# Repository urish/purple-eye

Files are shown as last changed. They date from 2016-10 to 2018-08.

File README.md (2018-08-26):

purple-eye
==========

> A web-bluetooth controlled 3d-printed dancing robot

Purple Eye

## Prerequisites

The Web Interface uses [Web Bluetooth](https://medium.com/@urish/start-building-with-web-bluetooth-and-progressive-web-apps-6534835959a6) and is available on Chrome on the following platforms:

* Android 6.0 or newer
* Mac OS X 10.10 or newer
* Recent Linux ([see here for details](https://acassis.wordpress.com/2016/06/28/how-to-get-chrome-web-bluetooth-working-on-linux/))
* Windows 10 (Chrome Canary only)
* Chrome OS

[Online Web Interface](https://urish.github.io/purple-eye/)

## Hardware

➡ [Read how to make your own "Purple Eye" robot](https://medium.com/@urish/making-purple-eye-diy-dancing-robot-fa03d0f658e2#.q7gzas4cq)

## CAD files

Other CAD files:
model/purple-eye.blend

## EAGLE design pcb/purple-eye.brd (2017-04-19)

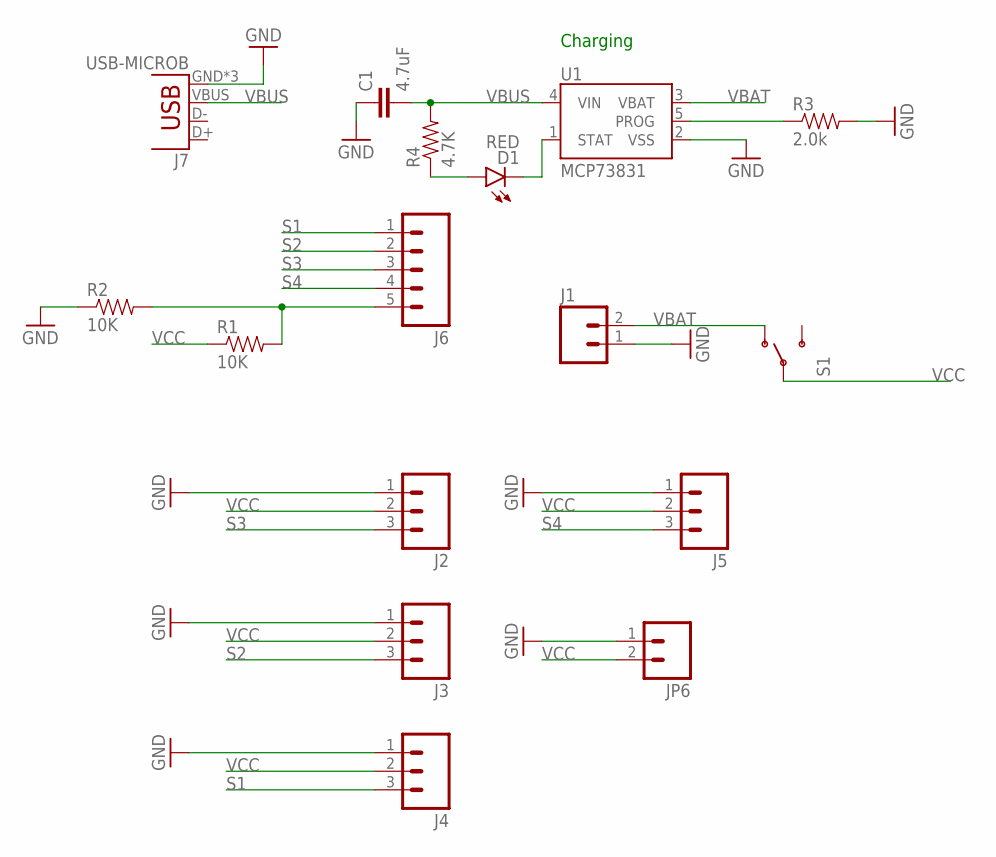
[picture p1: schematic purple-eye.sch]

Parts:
C1: 4.7uF; 0603-CAP
D1: RED; LED-0603
J1: M02JST-PTH-2; JST-2-PTH
J2, J3, J4, J5: M03LOCK; 1X03_LOCK
J6: M05LOCK; 1X05_LOCK
J7: USB-MICROB
JP6: M02LOCK; 1X02_LOCK
R1, R2: 10K; 0603-RES
R3: 2.0k; 0603-RES
R4: 4.7K; 0603-RES
S1: SWITCH-SPDTPTH_LOCK; SWITCH-SPDT_LOCK.007S
U1: MCP73831; SOT23-5

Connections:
GND: C1.1, J1.1, J2.1, J3.1, J4.1, J5.1, J7.GND, J7.MT1 (GND), J7.MT2 (GND), JP6.1, R2.1, R3.2, U1.2 (VSS)
unnamed: J6.5, R1.2, R2.2
unnamed: R3.1, U1.5 (PROG)
unnamed: D1.A, R4.1
unnamed: D1.C, U1.1 (STAT)
S1: J4.3, J6.1
S2: J3.3, J6.2
S3: J2.3, J6.3
S4: J5.3, J6.4
VBAT: J1.2, S1.1 (O), U1.3 (VBAT)
VBUS: C1.2, J7.VBUS, R4.2, U1.4 (VIN)
VCC: J2.2, J3.2, J4.2, J5.2, JP6.2, R1.1, S1.2

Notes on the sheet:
Charging

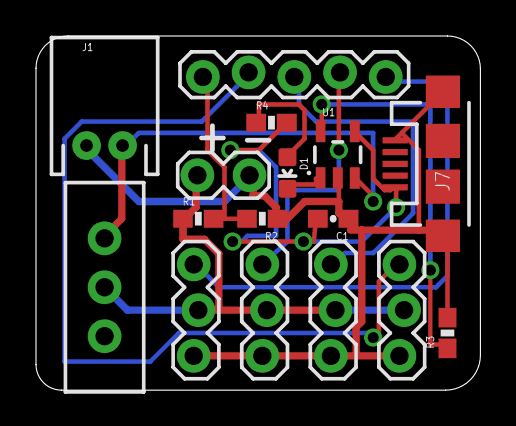
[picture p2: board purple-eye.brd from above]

Board: 2 copper layers, 24.7 x 19.7 mm, 16 parts (0 on the bottom side), 12 nets.

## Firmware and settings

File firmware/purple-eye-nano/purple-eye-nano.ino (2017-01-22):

/**
   Purple Eye Firmware ported to [BLE Nano](http://redbearlab.com/blenano/)
   Copyright (C) 2016, Uri Shaked
   License: MIT.
*/

extern "C" {
#include "pstorage.h"
#include "fstorage.h"
#include "softdevice_handler.h"
}

#include <BLE_API.h>
#include <Wire.h>
#include <LSM303.h>
#include <L3G.h>
#include "nrf51servo.h"

#define DEVICE_NAME       "PurpleEye"
#define RIGHT_LEG_PIN     D4
#define RIGHT_FOOT_PIN    D5
#define LEFT_FOOT_PIN     D6
#define LEFT_LEG_PIN      D7
#define BATTERY_LEVEL_PIN A5

// Physical Web
#define EDDYSTONE_SERVICE_UUID 0xFEAA
uint8_t eddystoneData[]  = {
  0xAA, 0xFE,  // Eddystone Service Id
  0x10,        // Frame type: URL
  0xF8,        // Power
  0x03,        // https://
  'b', 'i', 't', '.', 'd', 'o', '/', 'p', 'r', 'p', 'l',
};

// ng-beacon scanning parameters
#define RSSI_THRESHOLD -50
#define TARGET_DEVICE_NAME "ng-beacon"

BLE    ble;
static const uint16_t advertisedServices[] = { GattService::UUID_BATTERY_SERVICE, 0x5100, EDDYSTONE_SERVICE_UUID };

// Servos
Servo              leftFoot, rightFoot, leftLeg, rightLeg;
static uint8_t     servoValues[4]         = {0, 0, 0, 0};
GattCharacteristic servosChar(0x5200, servoValues, sizeof(servoValues), sizeof(servoValues), GattCharacteristic::BLE_GATT_CHAR_PROPERTIES_WRITE | GattCharacteristic::BLE_GATT_CHAR_PROPERTIES_WRITE_WITHOUT_RESPONSE);
static int8_t      servoOffsets[4]        = {0, 0, 0, 0};
GattCharacteristic servoOffsetsChar(0x5201, (uint8_t*)servoOffsets, sizeof(servoOffsets), sizeof(servoOffsets), GattCharacteristic::BLE_GATT_CHAR_PROPERTIES_READ | GattCharacteristic::BLE_GATT_CHAR_PROPERTIES_WRITE | GattCharacteristic::BLE_GATT_CHAR_PROPERTIES_WRITE_WITHOUT_RESPONSE);
GattCharacteristic *servosChars[] = {&servosChar, &servoOffsetsChar, };
GattService        servosService(0x5100, servosChars, sizeof(servosChars) / sizeof(GattCharacteristic *));

// Battery
Ticker             batteryTask;
static uint8_t     batteryLevel[1];
GattCharacteristic batteryLevelChar(GattCharacteristic::UUID_BATTERY_LEVEL_CHAR, batteryLevel, sizeof(batteryLevel), sizeof(batteryLevel), GattCharacteristic::BLE_GATT_CHAR_PROPERTIES_READ | GattCharacteristic::BLE_GATT_CHAR_PROPERTIES_NOTIFY);
GattCharacteristic *batteryServiceChars[] = {&batteryLevelChar };
GattService        batteryService(GattService::UUID_BATTERY_SERVICE, batteryServiceChars, sizeof(batteryServiceChars) / sizeof(GattCharacteristic *));

// Accelerometer + Magnetometer + Gyro (IMU)
LSM303             imuDevice;
bool               imuAvailable;
L3G                gyro;
bool               gyroAvailable;
static uint16_t    imuData[9] = {0, 0, 0, 0, 0, 0, 0, 0, 0};
GattCharacteristic imuChar(0xff09, (uint8_t*)imuData, sizeof(imuData), sizeof(imuData), GattCharacteristic::BLE_GATT_CHAR_PROPERTIES_READ | GattCharacteristic::BLE_GATT_CHAR_PROPERTIES_NOTIFY);
GattCharacteristic *imuChars[] = {&imuChar };
GattService        imuService(0xff08, imuChars, sizeof(imuChars) / sizeof(GattCharacteristic *));

// Sound
byte               playerData[] = {0, 0, 0};
GattCharacteristic playerChar(0xff1a, (uint8_t*)playerData, sizeof(playerData), sizeof(playerData), GattCharacteristic::BLE_GATT_CHAR_PROPERTIES_WRITE | GattCharacteristic::BLE_GATT_CHAR_PROPERTIES_WRITE_WITHOUT_RESPONSE);
GattCharacteristic *playerChars[] = {&playerChar };
GattService        playerService(0xff10, playerChars, sizeof(playerChars) / sizeof(GattCharacteristic *));

// Storage
bool               storageAvailable = false;
FS_SECTION_VARS_ADD(fs_config_t storageConfig) = { .cb = &storageCallback, .num_pages = 1, .page_order = 1 };

// Dancer
Ticker             danceTask;
int8_t             dancePosition = 0;
int8_t             danceDirection = 1;

void updateServos() {
  if (servoValues[0] == 0 && servoValues[1] == 0 && servoValues[2] == 0 && servoValues[3] == 0) {
    rightLeg.detach();
    rightFoot.detach();
    leftFoot.detach();
    leftLeg.detach();
  } else {
    if (!leftFoot.attached()) {
      rightLeg.attach(RIGHT_LEG_PIN);
      rightFoot.attach(RIGHT_FOOT_PIN);
      leftFoot.attach(LEFT_FOOT_PIN);
      leftLeg.attach(LEFT_LEG_PIN);
    }
    rightLeg.write(servoValues[0] + servoOffsets[0]);
    rightFoot.write(servoValues[1] + servoOffsets[1]);
    leftFoot.write(servoValues[2] + servoOffsets[2]);
    leftLeg.write(servoValues[3] + servoOffsets[3]);
  }
}

static void sysEventHandler(uint32_t sys_evt) {
  // Delegate events to the fstorage module, as well as pstorage (used by the RBL stack)
  fs_sys_event_handler(sys_evt);
  pstorage_sys_event_handler(sys_evt);
}

static void storageCallback(uint8_t op_code, uint32_t result, uint32_t  const * p_data, fs_length_t length) {
  if (op_code == FS_OP_ERASE && result == NRF_SUCCESS) {
    fs_store(&storageConfig, storageConfig.p_start_addr, (uint32_t*)servoOffsets, 1); // 1 words = 4 bytes
  }
}

void loadServoOffsets() {
  memcpy(servoOffsets, storageConfig.p_start_addr, sizeof(servoOffsets));
}

void saveServoOffsets() {
  fs_erase(&storageConfig, storageConfig.p_start_addr, FS_PAGE_SIZE_WORDS);
}

void playerCommand(byte cmd, byte arg1, byte arg2) {
  byte data[10] = {0x7e, 0xff, 0x6, cmd, 0, arg1, arg2, 0, 0, 0xef};
  int16_t checksum = 0 - data[1] - data[2] - data[3] - data[4] - data[5] - data[6];
  data[7] = (checksum >> 8) & 0xff;
  data[8] = checksum & 0xff;
  Serial.write(data, sizeof(data));
}

void playerCommand(byte cmd, uint16_t arg) {
  playerCommand(cmd, arg >> 8, arg & 0xff);
}

void playSound(uint16_t fileNum, byte volume) {
  if (volume > 0) {
    playerCommand(0x6, 0, volume);
    delay(10);
  }
  playerCommand(0x3, fileNum);
}

void disconnectionCallBack(const Gap::DisconnectionCallbackParams_t *params) {
  ble.startAdvertising();
  Serial.println("Disconnected :-(");
}

void gattServerWriteCallBack(const GattWriteCallbackParams *params) {
  if (params->handle == servosChar.getValueAttribute().getHandle()) {
    memcpy(servoValues, params->data, params->len);
    updateServos();
  }
  if (params->handle == servoOffsetsChar.getValueAttribute().getHandle()) {
    memcpy(servoOffsets, params->data, params->len);
    saveServoOffsets();
  }
  if ((params->handle == playerChar.getValueAttribute().getHandle()) && (params->len >= 2)) {
    uint16_t fileId = *(uint16_t*)params->data;
    uint8_t volume = params->len == 3 ? params->data[2] : 0;
    playSound(fileId, volume);
  }
}

void sensorsCallback() {
  if (ble.getGapState().connected) {
    // Battery Level
    float voltage = analogRead(BATTERY_LEVEL_PIN) * 3.3 / 512;
    batteryLevel[0] = max(0, min(100, (int)((voltage - 3.6) / 0.6 * 100)));
    ble.updateCharacteristicValue(batteryLevelChar.getValueAttribute().getHandle(), batteryLevel, sizeof(batteryLevel));

    // IMU
    if (imuAvailable) {
      imuDevice.read();
      memset(imuData, 0, sizeof(imuData));
      if (!imuDevice.timeoutOccurred()) {
        imuData[0] = imuDevice.a.x;
        imuData[1] = imuDevice.a.y;
        imuData[2] = imuDevice.a.z;
        imuData[3] = imuDevice.m.x;
        imuData[4] = imuDevice.m.y;
        imuData[5] = imuDevice.m.z;
      }
      if (gyroAvailable) {
        gyro.read();
        if (!gyro.timeoutOccurred()) {
          imuData[6] = gyro.g.x;
          imuData[7] = gyro.g.y;
          imuData[8] = gyro.g.z;
        }
      }
      ble.updateCharacteristicValue(imuChar.getValueAttribute().getHandle(), (uint8_t*)imuData, sizeof(imuData));
    }
  }
}

char *getDeviceName(const uint8_t *data, byte dlen) {
  static char result[16];
  byte index = 0;

  while (index + 1 < dlen) {
    byte field_len = data[index];
    byte field_type = data[index + 1];
    const void *field_data = &data[index + 2];
    index += field_len + 1;

    if (field_type == BLE_GAP_AD_TYPE_COMPLETE_LOCAL_NAME) {
      field_len--;
      if (field_len > 15) {
        field_len = 15;
      }
      memcpy(result, field_data, field_len);
      result[field_len] = 0;
      return result;
    }
  }

  return NULL;
}

unsigned long beaconLastSeen = millis();
void danceCallback() {
  if (millis() - 2000 > beaconLastSeen) {
    beaconLastSeen = 0;
    dancePosition = 0;
    danceTask.detach();
  }

  servoValues[0] = 90 + dancePosition;
  servoValues[1] = 90 + dancePosition;
  servoValues[2] = 90 + dancePosition;
  servoValues[3] = 90 + dancePosition;
  updateServos();

  dancePosition += danceDirection * 2;
  if (dancePosition > 20 || dancePosition < -20) {
    danceDirection = -danceDirection;
  }
}

void scanningCallback(const Gap::AdvertisementCallbackParams_t* params) {
  char *deviceName = getDeviceName((const uint8_t *)params->advertisingData, params->advertisingDataLen);
  if ((params->rssi > RSSI_THRESHOLD) && !strcmp(deviceName, TARGET_DEVICE_NAME)) {
    Serial.print("Found beacon, RSSI=");
    Serial.println(params->rssi, DEC);

    if (!beaconLastSeen) {
      danceTask.attach(danceCallback, 0.02);
    }
    beaconLastSeen = millis();
  }
}

void setup() {
  Serial.begin(9600);
  Serial.println("Purple Eye Nano!");

  // Set up storage - to store servo offsets
  // Following two lines are a workaround for a bug - storageConfig is not initialized correctly for some reason.
  // So we set up the configuration here, and override the original one.
  fs_config_t storageConfig2 = { .cb = storageCallback, .num_pages = 1, .page_order = 0 };
  memcpy(&storageConfig, &storageConfig2, sizeof(storageConfig));
  if (fs_init() == NRF_SUCCESS) {
    storageAvailable = true;
    loadServoOffsets();
  }

  Wire.begin();
  imuAvailable = imuDevice.init();
  imuDevice.setTimeout(1);
  imuDevice.enableDefault();
  gyroAvailable = gyro.init();
  gyro.setTimeout(1);
  gyro.enableDefault();

  // LED consumes about 0.3ma, so we turn it off.
  pinMode(LED, OUTPUT);
  digitalWrite(LED, 1);

  pinMode(BATTERY_LEVEL_PIN, INPUT);
  pinMode(RIGHT_LEG_PIN, OUTPUT);
  pinMode(RIGHT_FOOT_PIN, OUTPUT);
  pinMode(LEFT_FOOT_PIN, OUTPUT);
  pinMode(LEFT_LEG_PIN, OUTPUT);
  updateServos();

  ble.init();
  ble.onDisconnection(disconnectionCallBack);
  ble.onDataWritten(gattServerWriteCallBack);

  // Setup advertising payload, including Eddystone data
  ble.accumulateAdvertisingPayload(GapAdvertisingData::BREDR_NOT_SUPPORTED | GapAdvertisingData::LE_GENERAL_DISCOVERABLE);
  ble.accumulateAdvertisingPayload(GapAdvertisingData::COMPLETE_LIST_16BIT_SERVICE_IDS, (uint8_t*)advertisedServices, sizeof(advertisedServices));
  ble.accumulateAdvertisingPayload(GapAdvertisingData::SERVICE_DATA, (uint8_t*)eddystoneData, sizeof(eddystoneData));
  ble.accumulateScanResponse(GapAdvertisingData::COMPLETE_LOCAL_NAME, (uint8_t *)DEVICE_NAME, sizeof(DEVICE_NAME) - 1);
  ble.setAdvertisingType(GapAdvertisingParams::ADV_CONNECTABLE_UNDIRECTED);

  ble.addService(servosService);
  ble.addService(batteryService);
  ble.addService(imuService);
  ble.addService(playerService);
  ble.setDeviceName((const uint8_t *)DEVICE_NAME);
  ble.setTxPower(4);
  ble.setAdvertisingInterval(160); // (100 ms = 160 * 0.625ms.)
  ble.setAdvertisingTimeout(0);
  ble.startAdvertising();

  // scanning for ng-beacons
  ble.setScanParams(200, 100, 0, true);
  ble.startScan(scanningCallback);

  // Battery level task
  batteryTask.attach(sensorsCallback, 0.1);

  // Override the system event handler - this is required for fstorage
  softdevice_sys_evt_handler_set(sysEventHandler);
}

void loop() {
  ble.waitForEvent();
}

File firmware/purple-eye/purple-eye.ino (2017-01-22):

/*********************************************************************
  This is an example for our nRF51822 based Bluefruit LE modules

  Pick one up today in the adafruit shop!

  Adafruit invests time and resources providing this open source code,
  please support Adafruit and open-source hardware by purchasing
  products from Adafruit!

  MIT license, check LICENSE for more information
  All text above, and the splash screen below must be included in
  any redistribution
*********************************************************************/

#include <Arduino.h>

#include "Adafruit_BLE.h"
#include "Adafruit_BluefruitLE_SPI.h"
#include "Servo.h"

#define BLUEFRUIT_SPI_CS               8
#define BLUEFRUIT_SPI_IRQ              7
#define BLUEFRUIT_SPI_RST              4

#define RIGHT_LEG_PIN 5
#define RIGHT_FOOT_PIN 11
#define LEFT_FOOT_PIN 9
#define LEFT_LEG_PIN 10

const uint8_t BLE_ADVERTISE_PACKET[] = {
  // Eddystone URL Beacon. See https://www.mkompf.com/tech/eddystoneurl.html
  0x07,  // Length of Service List
  0x03,  // Param: Service List
  0x00, 0x51, // Purple Eye Service ID
  0x0a, 0x18, // Battery Level Service
  0xAA, 0xFE,  // Eddystone ID
  
  0x11,  // Length of Service Data
  0x16,  // Service Data
  0xAA, 0xFE, // Eddystone ID
  
  0x10,  // Frame type: URL
  0xF8, // Power
  0x02, // http://
  'b',
  'i',
  't',
  '.',
  'd',
  'o',
  '/',
  'p',
  'r',
  'p',
  'l',
};

Adafruit_BluefruitLE_SPI ble(BLUEFRUIT_SPI_CS, BLUEFRUIT_SPI_IRQ, BLUEFRUIT_SPI_RST);

Servo rightFoot, rightLeg, leftFoot, leftLeg;
int rightFootValue = 0, rightLegValue = 0, leftFootValue = 0, leftLegValue = 0;

void error(const __FlashStringHelper*err) {
  Serial.println(err);
  while (1);
}

void updateServos() {
  if (leftFootValue == 0 && leftLegValue == 0 && rightFootValue == 0 && rightFootValue == 0) {
    rightLeg.detach();
    rightFoot.detach();
    leftFoot.detach();
    leftLeg.detach();
  } else {
    if (!leftFoot.attached()) {
      rightLeg.attach(RIGHT_LEG_PIN);
      rightFoot.attach(RIGHT_FOOT_PIN);
      leftFoot.attach(LEFT_FOOT_PIN);
      leftLeg.attach(LEFT_LEG_PIN);
    }
    rightFoot.write(rightFootValue + 8);
    rightLeg.write(rightLegValue);
    leftFoot.write(leftFootValue - 10);
    leftLeg.write(leftLegValue);
  }
}

int32_t eyebotServiceId;
int32_t eyebotServosCharId;
int32_t batteryServiceId;
int32_t batteryLevelCharId;

void setup(void)
{
  boolean success;

  updateServos();

  Serial.begin(115200);
  Serial.println("Start!");

  randomSeed(micros());

  /* Initialise the module */
  Serial.print(F("Initialising the Bluefruit LE module: "));

  if ( !ble.begin(true) )
  {
    error(F("Couldn't find Bluefruit, make sure it's in CoMmanD mode & check wiring?"));
  }
  Serial.println( F("OK!") );

  /* Perform a factory reset to make sure everything is in a known state */
  Serial.println(F("Performing a factory reset: "));
  if (! ble.factoryReset() ) {
    error(F("Couldn't factory reset"));
  }

  /* Disable command echo from Bluefruit */
  ble.echo(false);

  Serial.println("Requesting Bluefruit info:");
  /* Print Bluefruit information */
  ble.info();

  /* Change the device name to make it easier to find */
  Serial.println("Setting device name");

  if (! ble.sendCommandCheckOK(F("AT+GAPDEVNAME=PurpleEye")) ) {
    error(F("Could not set device name?"));
  }

  /* Add the Servo Service definition */
  /* Service ID should be 1 */
  Serial.println(F("Adding the Servo service definition (UUID = 0x5100): "));
  success = ble.sendCommandWithIntReply( F("AT+GATTADDSERVICE=UUID=0x5100"), &eyebotServiceId);
  if (! success) {
    error(F("Could not add Servo service"));
  }

  /* Chars ID for Servo position should be 1 */
  Serial.println(F("Adding the Servo Position characteristic (UUID = 0x5200): "));
  success = ble.sendCommandWithIntReply( F("AT+GATTADDCHAR=UUID=0x5200, PROPERTIES=0x0A, MIN_LEN=4, MAX_LEN=4, VALUE=00-00-00-00"), &eyebotServosCharId);
  if (! success) {
    error(F("Could not add Servo characteristic"));
  }

  /* Add the Battery Service definition */
  /* Service ID should be 1 */
  Serial.println(F("Adding the service definition (UUID = 0x180F): "));
  success = ble.sendCommandWithIntReply( F("AT+GATTADDSERVICE=UUID=0x180F"), &batteryServiceId);
  if (! success) {
    error(F("Could not add Battery service"));
  }

  /* Chars ID for Battery Level should be 1 */
  Serial.println(F("Adding the characteristic (UUID = 0x2A19): "));
  success = ble.sendCommandWithIntReply( F("AT+GATTADDCHAR=UUID=0x2A19, PROPERTIES=0x12, MIN_LEN=1, MAX_LEN=1, VALUE=00"), &batteryLevelCharId);
  if (! success) {
    error(F("Could not add Battery Level characteristic"));
  }

  /* Add the Servo Service and Eddystone Beacon to the advertising data */
  Serial.println(F("Adding Servo Service UUID to the advertising payload: "));

  // Encode advertise packet as hex string
  char bleAdvStr[sizeof(BLE_ADVERTISE_PACKET) * 3];
  for (int i = 0; i < sizeof(BLE_ADVERTISE_PACKET); i++) {
    sprintf(&bleAdvStr[i * 3], "%02x-", BLE_ADVERTISE_PACKET[i]);
  };
  bleAdvStr[sizeof(bleAdvStr) - 1] = 0;
  char cmdBuf[256];
  snprintf(cmdBuf, sizeof(cmdBuf), "AT+GAPSETADVDATA=%s", bleAdvStr);
  ble.sendCommandCheckOK( cmdBuf );

  /* Reset the device for the new service setting changes to take effect */
  Serial.print(F("Performing a SW reset (service changes require a reset): "));
  ble.reset();

  Serial.println();
}

uint8_t lastBatteryLevel = 0;
void loop(void)
{
  float voltage = analogRead(A0) * 3.3 / 512;
  uint8_t batteryLevel = max(0, min(100, (voltage - 3.6) / 0.6 * 100));

  // Update Battery Level Charasteristic if necessary
  if (lastBatteryLevel != batteryLevel) {
    ble.print("AT+GATTCHAR=");
    ble.print(batteryLevelCharId);
    ble.print(",");
    ble.println(batteryLevel);
    ble.waitForOK();
    lastBatteryLevel = batteryLevel;
  };

  // Read servo values
  ble.print("AT+GATTCHAR=");
  ble.println(eyebotServosCharId);

  Serial.println(batteryLevel);

  char buf[100] = {0};
  ble.readline(buf, sizeof(buf));
  sscanf(buf, "%02x-%02x-%02x-%02x", &rightLegValue, &rightFootValue, &leftFootValue, &leftLegValue);
  updateServos();
}

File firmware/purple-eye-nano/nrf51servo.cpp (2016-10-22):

/** 
 *  nRF51 Servo Controller
 * 
 * Copyright (C) 2016, Uri Shaked.
 * 
 * License: MIT
 */

#include "softdevice_handler.h"
#include <Ticker.h>
#include <Arduino.h>

#include "nrf51servo.h"

#define SERVO_TIMESLOT_LENGTH  2500 // ms

static mbed::Ticker servo_task;
static uint8_t   servo_count = 0;
static uint8_t   servo_index = 0;
static Servo *servos[MAX_SERVOS] = {0};

static nrf_radio_signal_callback_return_param_t signal_callback_return_param = {0};

static nrf_radio_signal_callback_return_param_t * radio_callback(uint8_t signal_type)
{
  uint16_t next_tick = 0;
  uint16_t servo_tick_counter = 0;

  switch (signal_type)
  {
    case NRF_RADIO_CALLBACK_SIGNAL_TYPE_START:
      signal_callback_return_param.params.request.p_next = NULL;
      signal_callback_return_param.callback_action = NRF_RADIO_SIGNAL_CALLBACK_ACTION_END;

      servo_index++;
      if (servo_index >= servo_count) {
        servo_index = 0;
      }

      digitalWrite(servos[servo_index]->getPin(), HIGH);
      delayMicroseconds(servos[servo_index]->readMicroseconds());
      digitalWrite(servos[servo_index]->getPin(), LOW);
      break;

    case NRF_RADIO_CALLBACK_SIGNAL_TYPE_RADIO:
      signal_callback_return_param.params.request.p_next = NULL;
      signal_callback_return_param.callback_action = NRF_RADIO_SIGNAL_CALLBACK_ACTION_NONE;
      break;

    case NRF_RADIO_CALLBACK_SIGNAL_TYPE_TIMER0:
      signal_callback_return_param.callback_action = NRF_RADIO_SIGNAL_CALLBACK_ACTION_END;
      signal_callback_return_param.params.request.p_next = NULL;
      break;

    default:
      signal_callback_return_param.callback_action = NRF_RADIO_SIGNAL_CALLBACK_ACTION_NONE;
      signal_callback_return_param.params.request.p_next = NULL;
      break;
  }
  return (&signal_callback_return_param);
}

static nrf_radio_request_t   timeslot_request = {0};
static void servo_task_callback() {
  // Request a timeslot from the NRF firmware
  timeslot_request.request_type               = NRF_RADIO_REQ_TYPE_EARLIEST;
  timeslot_request.params.earliest.hfclk      = NRF_RADIO_HFCLK_CFG_DEFAULT;
  timeslot_request.params.earliest.priority   = NRF_RADIO_PRIORITY_NORMAL;
  timeslot_request.params.earliest.length_us  = SERVO_TIMESLOT_LENGTH;
  timeslot_request.params.earliest.timeout_us = 100000;
  sd_radio_request(&timeslot_request);
}

static void start_servo_task() {
  sd_radio_session_open(radio_callback);
  servo_task_callback();
  servo_task.attach_us(servo_task_callback, SERVO_REFRESH_INTERVAL);
}

static void stop_servo_task() {
  servo_task.detach();
  sd_radio_session_close();
}

Servo::Servo() {
  this->servoIndex = INVALID_SERVO;
  this->pulseWidth = DEFAULT_PULSE_WIDTH;
}

Servo::~Servo() {
  this->detach();
}

uint8_t Servo::attach(uint32_t pin) {
  bool first = (servo_count == 0);
  this->pin = pin;
  if ((this->servoIndex == INVALID_SERVO) && (servo_count < MAX_SERVOS)) {
    this->servoIndex = servo_count;
    servos[this->servoIndex] = this;
    servo_count++;
    pinMode(pin, OUTPUT);
    if (first) {
      start_servo_task();
    }
  }
  return this->servoIndex;
}

void Servo::detach() {
  if (this->servoIndex != INVALID_SERVO) {
    for (uint8_t i = this->servoIndex + 1; i < servo_count; i++) {
      servos[i] = servos[i - 1];
    }
    servo_count--;
    if (servo_count == 0) {
      stop_servo_task();
    }
  }
  this->servoIndex = INVALID_SERVO;
}

void Servo::write(uint16_t value) {
  value = map(value, 0, 180, MIN_PULSE_WIDTH, MAX_PULSE_WIDTH);
  this->writeMicroseconds(value);
}

void Servo::writeMicroseconds(uint16_t value) {
  if (value < MIN_PULSE_WIDTH) {
    value = MIN_PULSE_WIDTH;
  }
  if (value > MAX_PULSE_WIDTH) {
    value = MAX_PULSE_WIDTH;
  }
  this->pulseWidth = value;
}

uint16_t Servo::read() {
  return map(this->pulseWidth, MIN_PULSE_WIDTH, MAX_PULSE_WIDTH, 0, 180);
}

uint16_t Servo::readMicroseconds() {
  return this->pulseWidth;
}

bool Servo::attached() {
  return this->servoIndex != INVALID_SERVO;
}

uint32_t Servo::getPin() {
  return this->pin;
}

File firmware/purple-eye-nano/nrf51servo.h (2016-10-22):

/** 
 *  nRF51 Servo Controller
 * 
 * Copyright (C) 2016, Uri Shaked.
 * 
 * License: MIT
 */

#ifndef _NRF_SERVO_H
#define _NRF_SERVO_H

#include <inttypes.h>

#define MAX_SERVOS             10

#define INVALID_SERVO          255     // Value representing invalid servo index

// Min and max pulse length, in microseconds
#define MIN_PULSE_WIDTH        544     
#define MAX_PULSE_WIDTH        2400

#define SERVO_REFRESH_INTERVAL 10000   // Refresh servos every 10ms
#define DEFAULT_PULSE_WIDTH    1500     // default pulse width when servo is attached

class Servo {
  private:
    uint8_t servoIndex;
    uint16_t pulseWidth;
    uint32_t pin;
    
  public:
    Servo();
    ~Servo();
    
    uint8_t attach(uint32_t pin);
    void detach();
    
    void write(uint16_t value);
    void writeMicroseconds(uint16_t value);
    
    uint16_t read();
    uint16_t readMicroseconds();
    
    bool attached();    // return true if this servo is attached, otherwise false

    uint32_t getPin();
};

#endif /* _NRF_SERVO_H */

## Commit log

2016-05-20 add LiPo battery to list of hardware components
2016-06-14 Add Battery Service to Firmware
    adds support for measuring the remaining battery percentage by exposing a BLE Battery Service
2016-06-20 Display battery level indication
2016-07-10 Add Power Circuit PCB
    [purple-eye.brd, purple-eye.sch]
2016-08-10 Port firmware to the BLE Nano board
2016-08-12 Fixes in the BLE Nano firmware
    1. Implement "REST" mode (turn servos off)
    2. Correct battery level reporting
    3. Turn LED off to conserve power
    [purple-eye-nano.ino]
2016-08-14 Improve servo control accuracy on the nRF51
    The new servo code works in conjuction with the softdevice firmware to make sure servo timings are accurate on the nRF51822 chip.
2016-10-22 additional improvements to nrf51 servo code
2016-11-03 Remove the "Updating servos..." debug print
    Apparently, it messes up the servo control timing
2016-11-04 Add IMU sensor support
2016-12-08 Visualize robot orientation
    Using IMU data + three.js
    [purple-eye.blend]
2016-12-12 Add optional Gyro sensor
2016-12-12 Add persistence for servo offsets
    We use nrf's fstorage for storing 4 bytes, each contains offset correction for one of the servos
    [purple-eye-nano.ino]
2016-12-21 add 3d model of the robot head (blender)
    [purple-eye.blend]
2017-04-19 feat: add charging circuit
    [purple-eye.brd, purple-eye.sch]
2018-12-29 fix(firmware): Improve movement range
    [purple-eye-firmware.js]
2019-01-11 feat: new PCB (designed with EasyEDA)
    https://easyeda.com/uri_6323/purple-eye

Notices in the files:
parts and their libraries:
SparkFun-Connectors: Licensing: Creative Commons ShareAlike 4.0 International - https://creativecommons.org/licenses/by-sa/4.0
